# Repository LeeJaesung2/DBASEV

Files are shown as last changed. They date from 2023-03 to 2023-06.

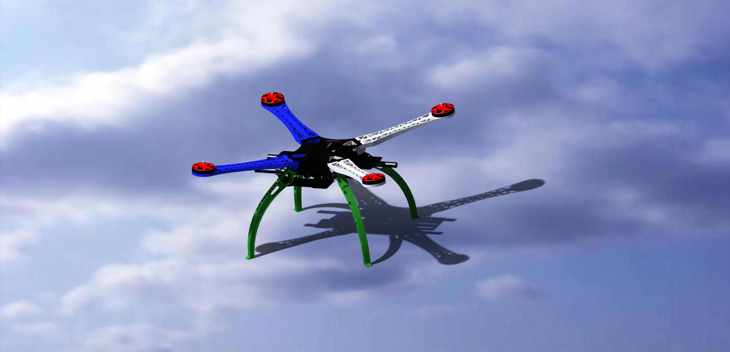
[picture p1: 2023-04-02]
Drone Modeling/Drone Modeling/test.jpg

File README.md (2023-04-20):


## 🚒🚑**드론을 이용한 긴급차량 지원 시스템**이란?

드론을 통해 긴급차량이 신속하게 사고현장에 도착하여 **골든타임**을 확보할 수 있는 긴급차량 지원 시스템 
<br><br>

## 📌 주요 기능
**긴급차량 추월로 확보**- 긴급차량보다 선행하여 전방 100M에서 차량들에게 긴급상황을 미리 알려줍니다.<br>
<br>



## 📆 개발 일정
기획 (23.02.20 ~ 23.03)<br>
제품 모델링 (23.03.27 ~ 23.)<br>
비행제어 SW (23.03.27 ~ 23.)<br>
제작 (23.04. ~ 23.)<br>
시험비행 (23. ~ 23.)<br>

## ⌨ How To Use?

### 1. 파이썬 2.7, ttb 설치
chomod +x install.sh <br />
./install.sh

### 2. 드론킷(droneKit) 설치
chomod +x dronekit.sh <br />
./dronekit.sh

### 3. 헤더파일 설치 (Linux)
sudo make install

### 4. 컴파일 (Linux)
sudo make

### 5. 실행
sudo make exedrone (드론 실행파일) <br />
sudo make exevhicle (차량 실행파일)

### 6. 실행파일 지우기
sudo make clean

## 😀 함께한 사람들
경상국립대학교 항공우주 및 소프트웨어공학과 18학번 이재성<br>
경상국립대학교 항공우주 및 소프트웨어공학과 18학번 이선호<br>
경상국립대학교 항공우주 및 소프트웨어공학과 22학번 이지훈<br>
경상국립대학교 항공우주 및 소프트웨어공학과 18학번 정승진<br>
경상국립대학교 항공우주 및 소프트웨어공학과 18학번 한규영

## 📗 참고 자료<br>
Notion : https://www.notion.so/Sky-Rescuers-cc621ae866ca4cde91c4affb1fb3adff<br>

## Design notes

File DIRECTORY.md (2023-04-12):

DBASEV   
├── build
|    ├── drivers 
|    ├── modules 
├── docs -- 문서
├── Dron Modeling 
├── pixhawk  
|    ├── Documentation 
|    ├── example 
├── python_src -- python 코드
├── rasberryPi -- 라즈베리파이 코드  
|    ├── drone -- 드론 코드  
|    ├── vehicle -- 차량 코드  
├── src 소스코드  
|    ├── drivers -- 장치 세팅  
|    ├── examples -- 예제코드  
|    ├── include -- 라이브러리 목록  
|    ├── modules -- 기능 구현 코드  
├── test -- 테스트 코드  
├── test_data -- 테스트 데이터  
├── Makefile  
├── README.md

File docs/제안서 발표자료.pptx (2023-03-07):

## 자율비행 드론을 이용한 긴급차량 지원 시스템 S A V e D

System for Assistancd emergency Vehicle traffic using autonomos flying Drone

이재성 2018011889
이선호 2018011886
이지훈 2022080184
정승진 2018011911
한규영 2018011939

## CONTENTS

1. 추진배경
2. 목표
3. 기업의 요구도
4. 개발 내용
5. 결과물
6. 기대효과
7. 현실적 제한요소
8. 팀 구성 및 역할 분담
9. 예산 및 일정

## 추진 배경

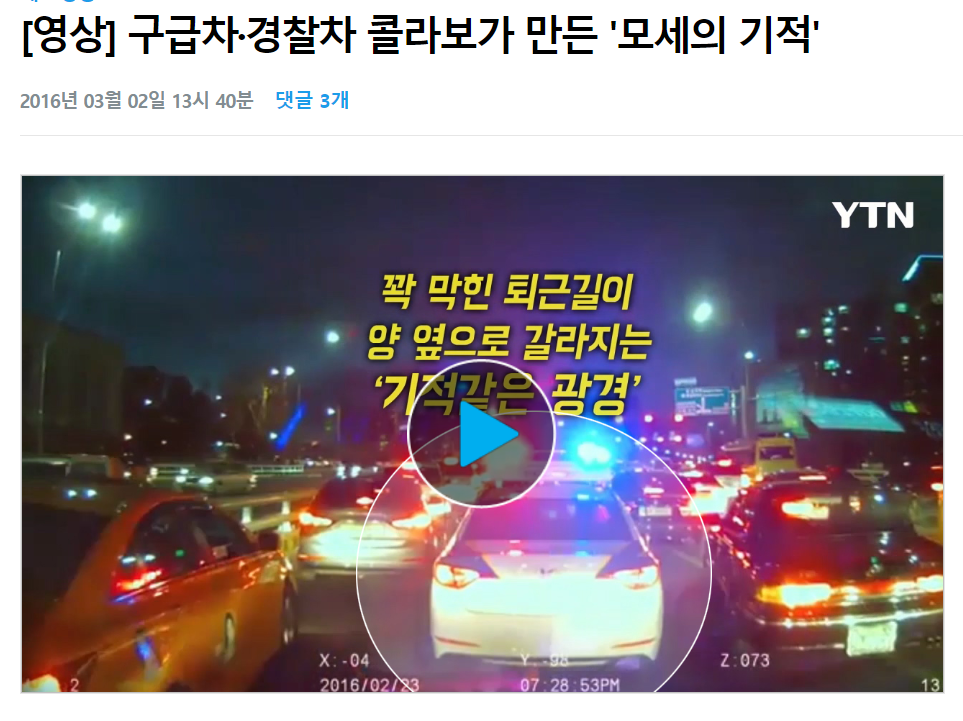
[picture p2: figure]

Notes: http://www.headlinejeju.co.kr/news/articleView.html?idxno=493822
http://www.ihalla.com/article.php?aid=1660275907730641044
https://news.sbs.co.kr/news/endPage.do?news_id=N1006625344&plink=ORI&cooper=NAVER

## 추진 배경

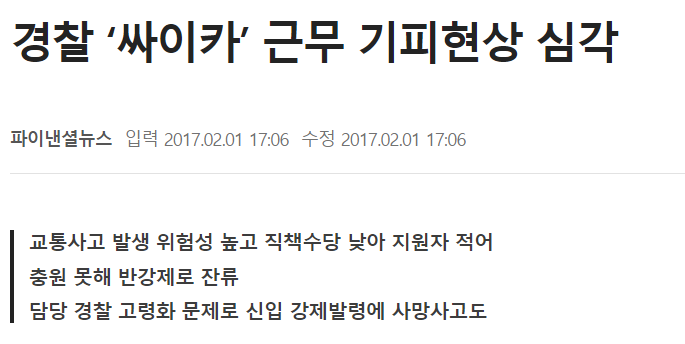
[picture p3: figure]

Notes: https://www.fnnews.com/news/201702011706314263

## 과제의 목표

## 기업 요구도

## 개발 내용

## 결과물

## 기대 효과

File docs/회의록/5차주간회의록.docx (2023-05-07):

주 간 회 의 록

팀 명 | Sky Rescuers | 차수 | 5차
일 시 | 2023년 5월 7일 일요일 18시 30분
장 소 | 창업보육센터 C동 102호
참석자 | 이재성, 이선호, 이지훈, 정승진, 한규영
불참자
주요안건 | 물품 추가주문, 진행상황 공유

회의내용

- 지난주 진행상황
1. 드론 납땜 및 조립
2. 미션플래너 Navigation, Do 명령어 정리 및 각각 파라미터 설정 후 데이터 포맷 작성
3. 속도조절 알고리즘, next stoppoint설정 알고리즘, 통신오류에 대한 알고리즘 작성
4. Thread간 concurrent queue 연결
5. python코드를 임베딩하는 Makefile 수정
- 이번주 진행상황 (진행상황을 나타내는 사진 등 첨부)
1. 추가 물품 주문 (GPS, 자이로센서, 피에조 부저, 네오픽셀 등)
2. 설계 변경에 의한 메세지큐 연결
3. matlab을 이용한 차량과 드론의 거리 유지 제어 블럭도 제작
4. 비행 소프트웨어의 소프트웨어 추가 구현 및 코드 리펙토링
5. GPS를 이용한 차량 속력 계산 프로그램 구현
6. 탑재체 부착 케이스 모델링
7. 드론 켈리브레이션 조정 완료
- 문제점
1. 도로 상황을 가정한 시뮬레이션 방안 필요
2. 커넥트 문제를 해결 후 테스트 필요
3. 메세지 큐를 C++에서 정보 생성후 python에서 받아야 하는데 python 코드에서 하드웨어를 건드리는데 어려움이 있음
- 해결방안

1. posix_ipc라이브러리를 이용하여 큐에 접근해야함

2. unity를 이용한 시뮬레이션, 더미데이터를 이용한 시뮬레이션

- 팀원 별 실천사항(각 팀원에 부여된 역할을 명확히 명시할 것)

메세지 큐를 이용하기 위한 C++ producer code 작성

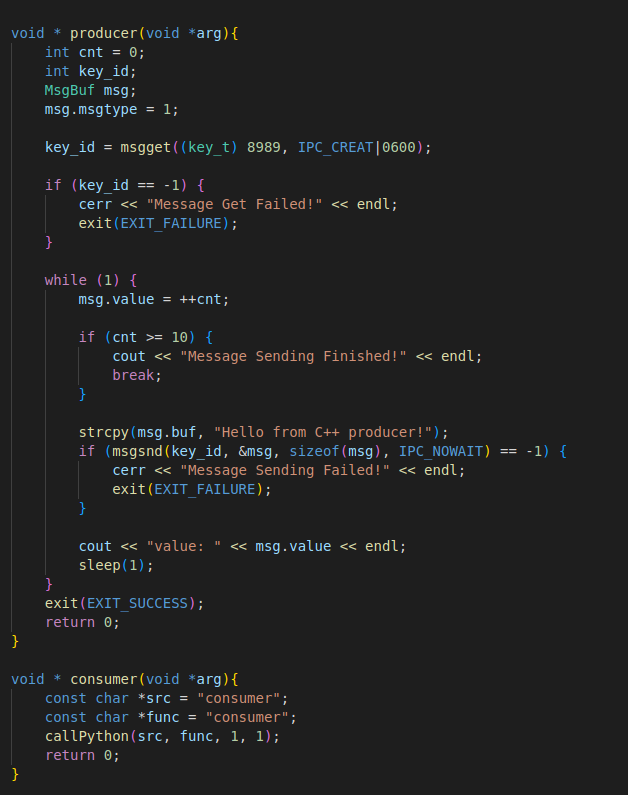
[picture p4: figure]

python consumer code 작성

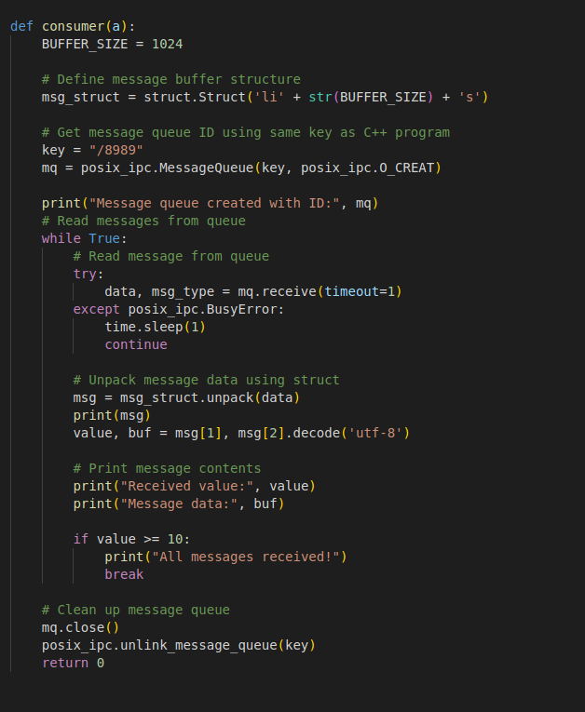
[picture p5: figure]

두 프로그램을 멀티 스레드 프로그램을 이용하여 실행 결과

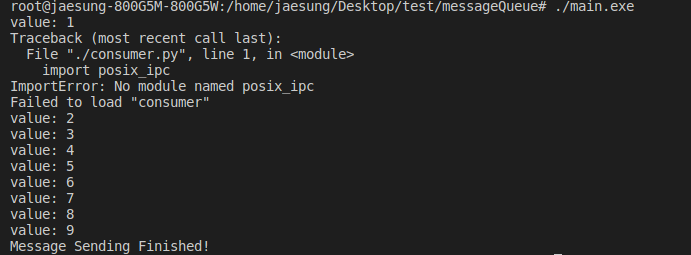
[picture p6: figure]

producer 코드에서 push 작동은 확인 하였지만 python 코드에서는 큐의 접근이 되지 않음

posix_ipc 라이브러리를 이용하여 자원에 접근하는 코드를 작성해야함

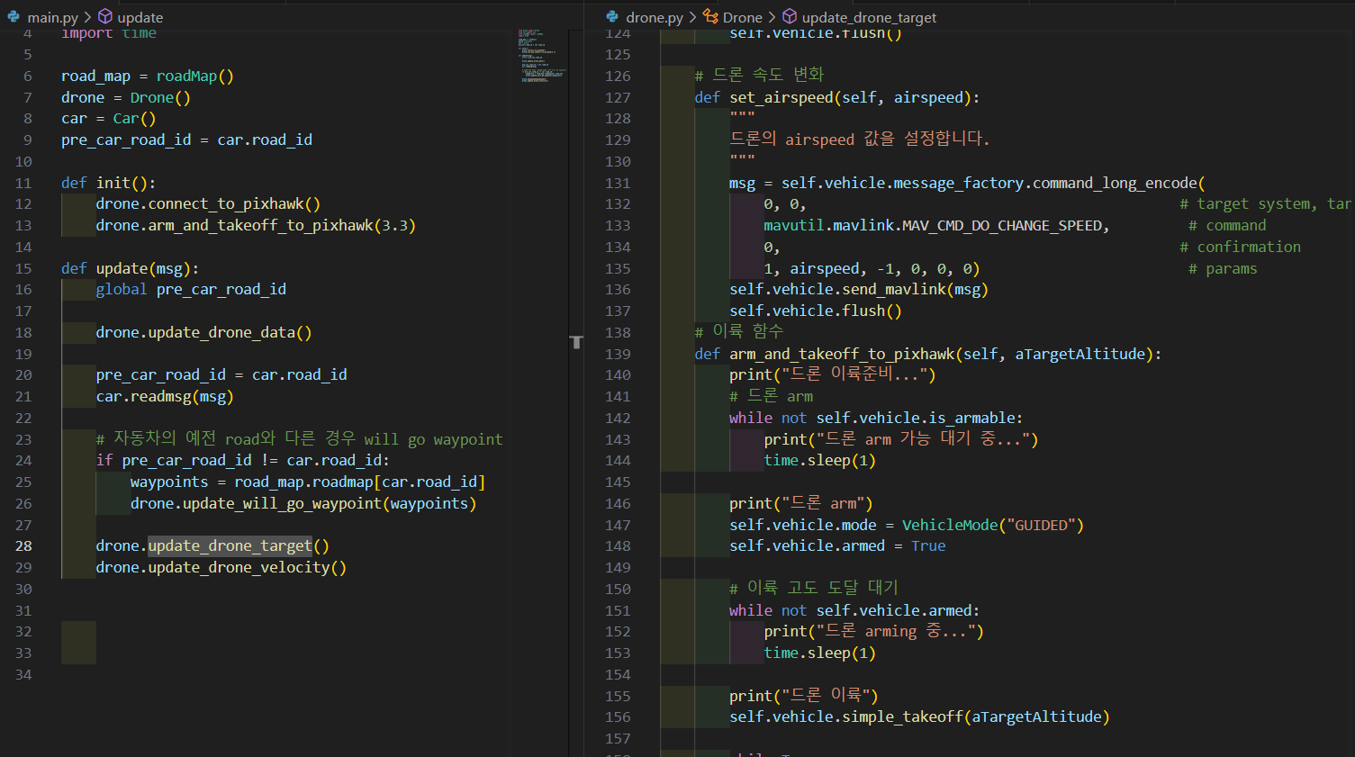
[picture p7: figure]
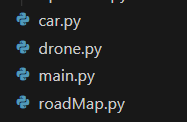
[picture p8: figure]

drone, car, road_map 객체를 만들었다. 이전에는 객체를 사용하지 않아서 코드의 흐름이 복잡하고 코드를 수정하기 힘들었다. 또한 실제 사용하는 코드에서는 plot부분이나 plot을 그리기위한 데이터들은 필요 없기에 그러한 부분들을 제거하고 객체를 만듬으로써 유지보수성을 키웠다.

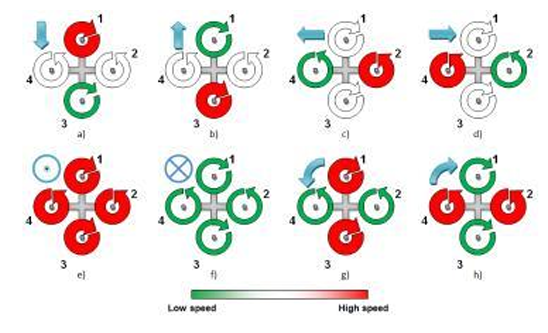
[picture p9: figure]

● 쿼드콥터의 각 모터의 추력의 세기에 대하여 운동방정식을 만들어야한다.

이때 전진비행에 대하여 운동방정식을 구할때 위의 그림에서의 첫번째 쿼드콥터와 같이 1번 모터를 강하게 2,4번은 동일한 힘으로 3번은 약하게 출력해야하지만, 가정하는 운동방정식에서는 1번을 강하게, 2,3,4번 모터을 동일한 힘으로 출력해주어 다음과 같은 운동방정식을 만들었다.

y=((F_1 +3F_0)/m)sin∅

다음 식을 선형화하여 matlab에서 제어 블럭도를 제작하였다.

sin∅ ≈ ∅

y = ((F_1 +3F_0)/m)d∅

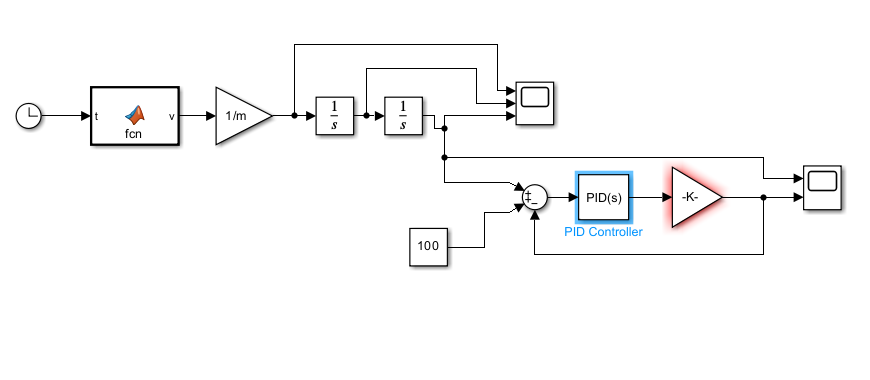
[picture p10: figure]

다음은 차량의 운동방정식에 대한 그래프를 표현하였다.

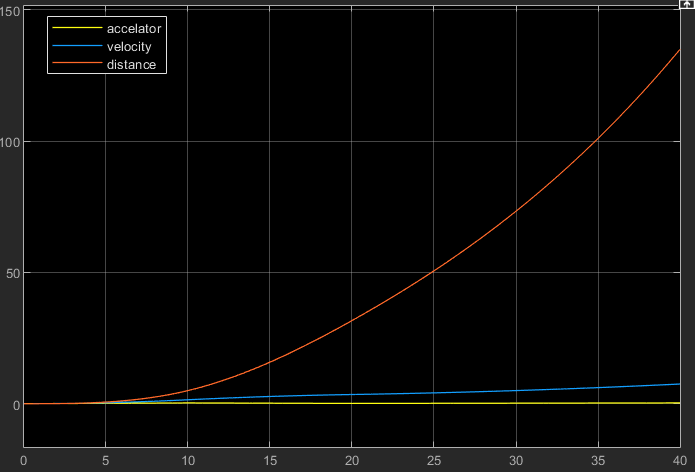
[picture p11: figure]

● 라즈베리파이 부착 아크릴 케이스 모델링

-라즈베리파이가 픽스호크 밑 프레임에 탑재가 불가능하다고 판단하여, 아크릴과 서포트 볼트를 이용하여, 라즈베리파이를 부착할 예정임.

그리고 다른 탑재체들도 다양하게 적용을 시킬 수 있음.

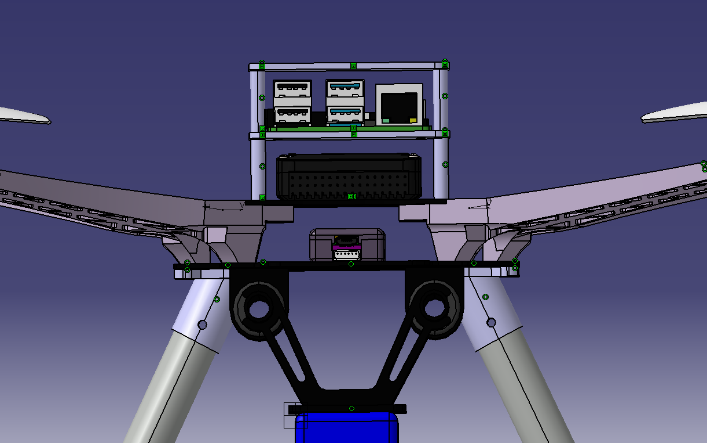
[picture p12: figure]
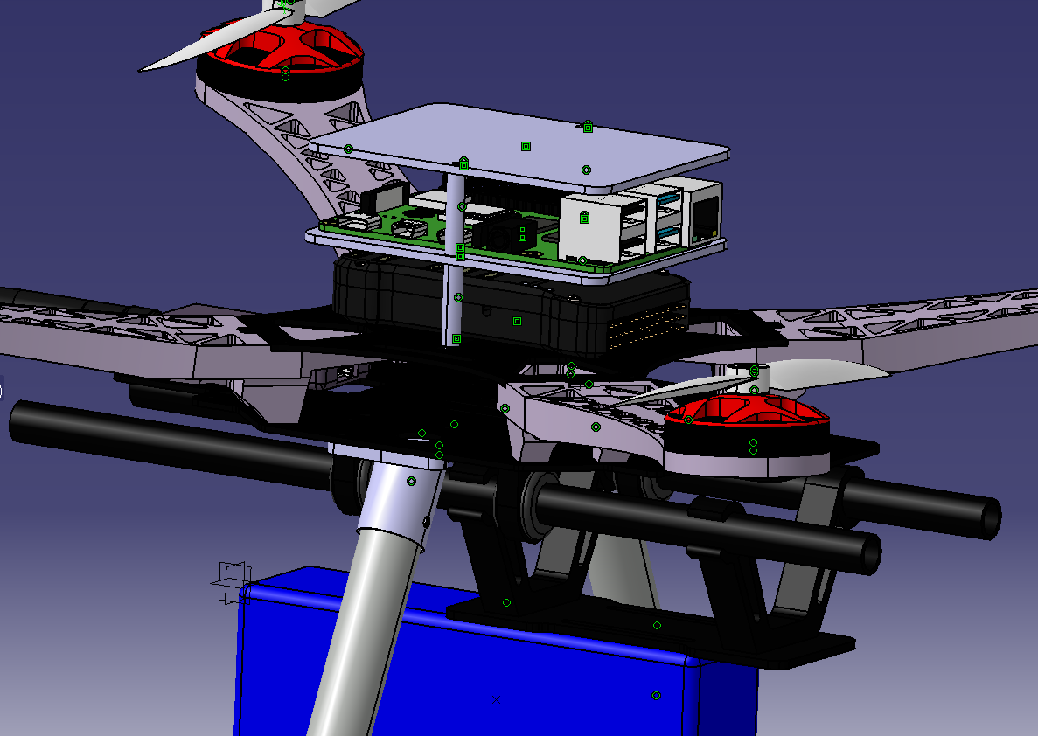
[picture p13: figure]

아크릴을 레이저 프린트로 커팅할 예정임으로, 캐드파일도 생성함.

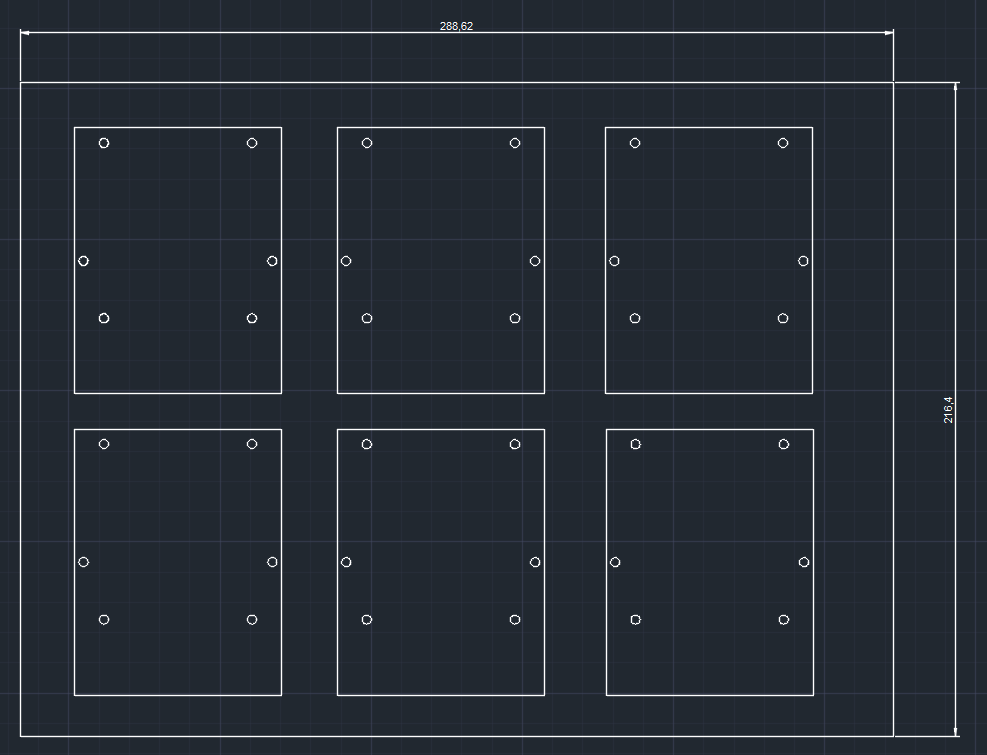
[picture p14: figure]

● GPS를 이용한 차량 속력 계산 프로그램 구현

‘Haversine’ 수식

: 항법에서 사용되는 방정식으로 지구와 같은 구의 표면 상에서 두 점 사이의 거리구할 수 있음

먼저 위도와 경도를 각각 degree 단위에서 radian 단위로 변환해야함. 그 후에 위도와 경도를 이용하여 거리를 구하고 있으며, 두 gps의 시간 term을 이용해 속력을 구하고 있음.

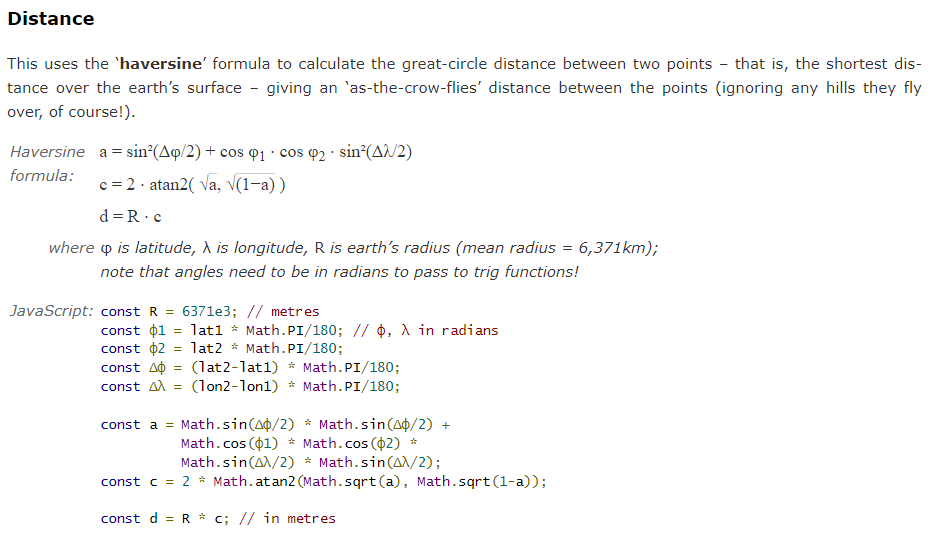
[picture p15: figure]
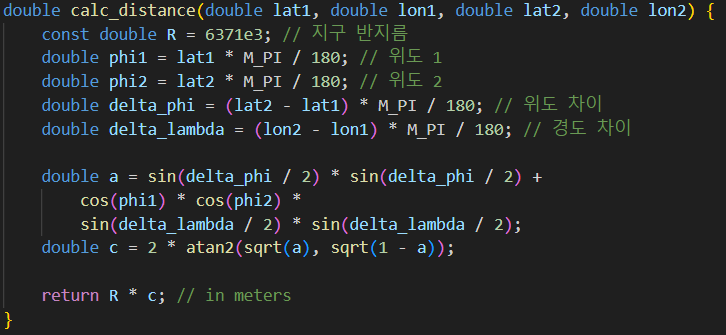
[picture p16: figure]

다음 모임 시간/장소: 2023년 5월 12일 금

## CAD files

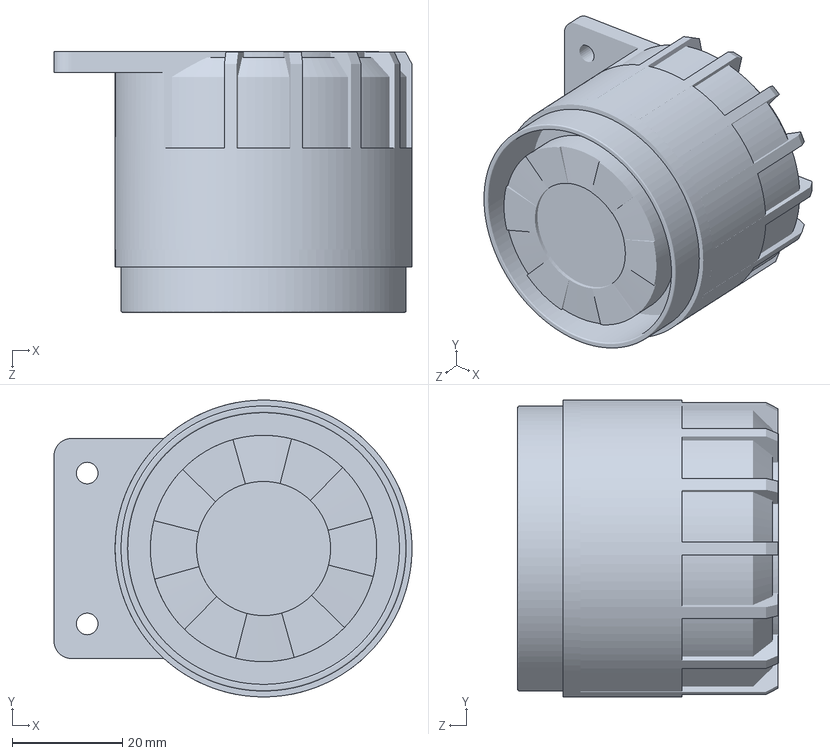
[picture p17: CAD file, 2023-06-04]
drone part/새 폴더/1234.SLDPRT
65.1 x 54.0 x 47.4 mm

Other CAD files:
Drone Modeling/Drone Modeling/5040 prop cw.CATPart
Drone Modeling/Drone Modeling/5040PropCCW.CATPart
Drone Modeling/Drone Modeling/5040prop.CATPart
Drone Modeling/Drone Modeling/Battery Plate Support.CATPart
Drone Modeling/Drone Modeling/Battery Plate.CATPart
Drone Modeling/Drone Modeling/Bottom Plate.CATPart
Drone Modeling/Drone Modeling/Leg.CATPart
Drone Modeling/Drone Modeling/Part27.CATPart
Drone Modeling/Drone Modeling/Part28.CATPart
Drone Modeling/Drone Modeling/Part29.CATPart
Drone Modeling/Drone Modeling/Part30.CATPart
Drone Modeling/Drone Modeling/Part31.CATPart
Drone Modeling/Drone Modeling/Part32.CATPart
Drone Modeling/Drone Modeling/Part33.CATPart
Drone Modeling/Drone Modeling/Part34.CATPart
Drone Modeling/Drone Modeling/Part35.CATPart
Drone Modeling/Drone Modeling/Part36.CATPart
Drone Modeling/Drone Modeling/Part43.CATPart
Drone Modeling/Drone Modeling/Part44.CATPart
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

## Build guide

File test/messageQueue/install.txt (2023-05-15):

pip install posix_ipc==1.0.4
pip install sysv-ipc==1.0.1

https://github.com/kiyoon/C_python_ipc/blob/master/receiver.py

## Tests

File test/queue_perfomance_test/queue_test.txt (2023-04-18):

install ttb using ttb.sh

copile option
g++ concurrent_queue.cpp -pthread -ltbb -std=c++14

change Max and test

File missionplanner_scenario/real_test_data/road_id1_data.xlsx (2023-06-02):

road_id | waypoint_id | lat | lon | alt
1 | 1 | 35.1554345 | 128.1040969 | 3
1 | 2 | 35.1553926 | 128.1041161 | 3
1 | 3 | 35.1553504 | 128.1041358 | 3
1 | 4 | 35.1553084 | 128.104155 | 3
1 | 5 | 35.1552665 | 128.1041744 | 3
1 | 6 | 35.155224 | 128.1041938 | 3
1 | 7 | 35.1551821 | 128.1042133 | 3
1 | 8 | 35.1551398 | 128.1042324 | 3
1 | 9 | 35.1550982 | 128.1042529 | 3
1 | 10 | 35.155056 | 128.1042726 | 3
1 | 11 | 35.155014 | 128.1042911 | 3
1 | 12 | 35.1549721 | 128.1043098 | 3
1 | 13 | 35.1549304 | 128.1043303 | 3
1 | 14 | 35.1548882 | 128.1043484 | 3
1 | 15 | 35.1548469 | 128.1043689 | 3
1 | 16 | 35.1548046 | 128.1043888 | 3
1 | 17 | 35.1547624 | 128.1044084 | 3
1 | 18 | 35.1547202 | 128.1044262 | 3
1 | 19 | 35.1546788 | 128.1044466 | 3
1 | 20 | 35.1546363 | 128.1044658 | 3
1 | 21 | 35.1545946 | 128.1044852 | 3
1 | 22 | 35.1545524 | 128.104505 | 3
1 | 23 | 35.1545105 | 128.1045241 | 3
1 | 24 | 35.1544685 | 128.1045432 | 3
1 | 25 | 35.1544269 | 128.1045633 | 3
1 | 26 | 35.1543852 | 128.1045824 | 3

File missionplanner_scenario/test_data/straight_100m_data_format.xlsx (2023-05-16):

road_id | waypoint_id | latitude(위도) | longtitude(경도) | altitude
1 | 1 | 35.1535098 | 128.1002861 | 5
1 | 2 | 35.1535017 | 128.1003405 | 5
1 | 3 | 35.153494 | 128.1003952 | 5
1 | 4 | 35.1534847 | 128.1004491 | 5
1 | 5 | 35.153477 | 128.1005038 | 5
1 | 6 | 35.1534693 | 128.1005578 | 5
1 | 7 | 35.1534608 | 128.1006118 | 5
1 | 8 | 35.1534523 | 128.1006654 | 5
1 | 9 | 35.1534447 | 128.1007197 | 5
1 | 10 | 35.1534351 | 128.100773 | 5
1 | 11 | 35.1534271 | 128.1008267 | 5
1 | 12 | 35.1534208 | 128.1008813 | 5
1 | 13 | 35.1534126 | 128.100935 | 5
1 | 14 | 35.1534038 | 128.1009893 | 5
1 | 15 | 35.1533948 | 128.1010436 | 5
1 | 16 | 35.1533868 | 128.1010972 | 5
1 | 17 | 35.1533789 | 128.1011509 | 5
1 | 18 | 35.1533701 | 128.1012052 | 5
1 | 19 | 35.1533613 | 128.1012592 | 5
1 | 20 | 35.1533517 | 128.1013132 | 5
1 | 21 | 35.1533446 | 128.1013675 | 5
1 | 22 | 35.1533369 | 128.1014218 | 5
1 | 23 | 35.1533298 | 128.1014758 | 5
1 | 24 | 35.153321 | 128.1015294 | 5
1 | 25 | 35.1533134 | 128.1015834 | 5
1 | 26 | 35.1533043 | 128.1016374 | 5
1 | 27 | 35.1532961 | 128.101691 | 5
1 | 28 | 35.1532879 | 128.1017447 | 5
1 | 29 | 35.1532796 | 128.1017993 | 5
1 | 30 | 35.15327 | 128.1018529 | 5
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

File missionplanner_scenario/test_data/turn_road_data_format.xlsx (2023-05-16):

road_id | waypoint_id | latitude(위도) | longtitude(경도) | altitude
1 | 1 | 35.1535098 | 128.1002861 | 5
1 | 2 | 35.1535017 | 128.1003405 | 5
1 | 3 | 35.153494 | 128.1003952 | 5
1 | 4 | 35.1534847 | 128.1004491 | 5
1 | 5 | 35.153477 | 128.1005038 | 5
1 | 6 | 35.1534693 | 128.1005578 | 5
1 | 7 | 35.1534608 | 128.1006118 | 5
1 | 8 | 35.1534523 | 128.1006654 | 5
1 | 9 | 35.1534447 | 128.1007197 | 5
1 | 10 | 35.1534351 | 128.100773 | 5
1 | 11 | 35.1534271 | 128.1008267 | 5
1 | 12 | 35.1534208 | 128.1008813 | 5
1 | 13 | 35.1534126 | 128.100935 | 5
1 | 14 | 35.1534038 | 128.1009893 | 5
1 | 15 | 35.1533948 | 128.1010436 | 5
1 | 16 | 35.1533868 | 128.1010972 | 5
1 | 17 | 35.1533789 | 128.1011509 | 5
1 | 18 | 35.1533701 | 128.1012052 | 5
1 | 19 | 35.1533613 | 128.1012592 | 5
1 | 20 | 35.1533517 | 128.1013132 | 5
1 | 21 | 35.1533446 | 128.1013675 | 5
1 | 22 | 35.1533369 | 128.1014218 | 5
1 | 23 | 35.1533298 | 128.1014758 | 5
1 | 24 | 35.153321 | 128.1015294 | 5
1 | 25 | 35.1533134 | 128.1015834 | 5
1 | 26 | 35.1533043 | 128.1016374 | 5
1 | 27 | 35.1532961 | 128.101691 | 5
1 | 28 | 35.1532879 | 128.1017447 | 5
1 | 29 | 35.1532796 | 128.1017993 | 5
1 | 30 | 35.15327 | 128.1018529 | 5
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

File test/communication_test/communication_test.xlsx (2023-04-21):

 |  |  |  |  |  |  |  |  |  | avg
 |  |  |  |  |  | 5119 | 7935 | 5887 | 9983 | 7231
msec | 100 | 300 | 500 | 700 | 1000
1 | 83 | 169 | 198 | 120 | 357
2 | 98 | 85 | 85 | 234 | 283
3 | 83 | 79 | 68 | 170 | 226
4 | 86 | 206 | 78 | 194 | 312
5 | 89 | 85 | 84 | 170 | 170
6 | 83 | 149 | 170 | 164 | 288
7 | 92 | 85 | 79 | 204 | 363
8 | 84 | 85 | 163 | 170 | 303
9 | 85 | 68 | 120 | 198 | 195
10 | 83 | 122 | 170 | 227 | 227
 | 9983 | 9216 | 9983 | 8275 | 9984
 | 9983 | 9984 | 9984 | 9983 | 9983
 | 9984 | 10239 | 9727 | 9728 | 9727
AVG
 | 100 | 300 | 500 | 700 | 1000
 | 86.6 | 113.3 | 121.5 | 185.1 | 272.4
 | 9380 | 9813 | 9750 | 9328.666667 | 9898

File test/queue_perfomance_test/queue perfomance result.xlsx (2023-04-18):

 | concurrent queuq | queue |  | concurrent queuq | queue |  |  | concurrent queuq | queue |  | concurrent queuq | queue |  | concurrent queuq | queue |  | concurrent queuq | queue
10K | 7 | 4 | 100K | 45 | 47 |  | 1M | 427 | 455 | 10M | 4104 | 4115 | 100M | 41542 | 44172 | 1B | 416650 | 411778
 | 9 | 5 |  | 44 | 46 |  |  | 420 | 492 |  | 4085 | 4896 |  | 42273 | 44997 |  | 409122 | 421276
 | 4 | 5 |  | 50 | 52 |  |  | 421 | 471 |  | 4037 | 5019 |  | 40285 | 45412
 | 4 | 5 |  | 47 | 54 |  |  | 422 | 488 |  | 4095 | 4398 |  | 40867 | 48428
 | 5 | 4 |  | 45 | 51 |  |  | 421 | 439 |  | 4097 | 4592 |  | 41472 | 49453
 | 4 | 4 |  | 48 | 48 |  |  | 422 | 447 |  | 4186 | 4584 |  | 40264 | 46746
 | 5 | 4 |  | 43 | 45 |  |  | 428 | 519 |  | 4233 | 4593 |  | 41094 | 46337
 | 9 | 5 |  | 48 | 50 |  |  | 422 | 422 |  | 4104 | 4285 |  | 40322 | 42703
 | 6 | 5 |  | 44 | 50 |  |  | 419 | 472 |  | 4070 | 4204 |  | 39759 | 42728
 | 5 | 5 |  | 43 | 49 |  |  | 416 | 423 |  | 4152 | 4266 |  | 39860 | 44409
 | 5.8 | 4.6 |  | 45.7 | 49.2 |  |  | 421.8 | 462.8 |  | 4116.3 | 4495.2 |  | 40773.8 | 45538.5 |  | 412886 | 416527
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

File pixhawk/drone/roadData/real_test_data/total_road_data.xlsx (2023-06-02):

road_id | waypoint_id | lat | lon | alt
1 | 1 | 35.1554345 | 128.1040969 | 3
1 | 2 | 35.1553926 | 128.1041161 | 3
1 | 3 | 35.1553504 | 128.1041358 | 3
1 | 4 | 35.1553084 | 128.104155 | 3
1 | 5 | 35.1552665 | 128.1041744 | 3
1 | 6 | 35.155224 | 128.1041938 | 3
1 | 7 | 35.1551821 | 128.1042133 | 3
1 | 8 | 35.1551398 | 128.1042324 | 3
1 | 9 | 35.1550982 | 128.1042529 | 3
1 | 10 | 35.155056 | 128.1042726 | 3
1 | 11 | 35.155014 | 128.1042911 | 3
1 | 12 | 35.1549721 | 128.1043098 | 3
1 | 13 | 35.1549304 | 128.1043303 | 3
1 | 14 | 35.1548882 | 128.1043484 | 3
1 | 15 | 35.1548469 | 128.1043689 | 3
1 | 16 | 35.1548046 | 128.1043888 | 3
1 | 17 | 35.1547624 | 128.1044084 | 3
1 | 18 | 35.1547202 | 128.1044262 | 3
1 | 19 | 35.1546788 | 128.1044466 | 3
1 | 20 | 35.1546363 | 128.1044658 | 3
1 | 21 | 35.1545946 | 128.1044852 | 3
1 | 22 | 35.1545524 | 128.104505 | 3
1 | 23 | 35.1545105 | 128.1045241 | 3
1 | 24 | 35.1544685 | 128.1045432 | 3
1 | 25 | 35.1544269 | 128.1045633 | 3
1 | 26 | 35.1543852 | 128.1045824 | 3
2 | 1 | 35.1543528 | 128.1045948 | 3
2 | 2 | 35.1543109 | 128.1046136 | 3
2 | 3 | 35.154269 | 128.1046327 | 3
2 | 4 | 35.1542267 | 128.1046525 | 3
2 | 5 | 35.1541848 | 128.1046719 | 3
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

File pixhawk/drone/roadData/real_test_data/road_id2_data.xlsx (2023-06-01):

road_id | waypoint_id | latitude(위도) | longtitude(경도) | altitude
2 | 1 | 35.1543528 | 128.1045948 | 3
2 | 2 | 35.1543109 | 128.1046136 | 3
2 | 3 | 35.154269 | 128.1046327 | 3
2 | 4 | 35.1542267 | 128.1046525 | 3
2 | 5 | 35.1541848 | 128.1046719 | 3
2 | 6 | 35.1541423 | 128.1046911 | 3
2 | 7 | 35.1541135 | 128.1047038 | 3

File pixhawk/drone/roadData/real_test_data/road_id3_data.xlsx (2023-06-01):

road_id | waypoint_id | latitude(위도) | longtitude(경도) | altitude
3 | 1 | 35.1543841 | 128.1046156 | 3
3 | 2 | 35.1543956 | 128.1046688 | 3
3 | 3 | 35.1544071 | 128.1047219 | 3
3 | 4 | 35.1544186 | 128.1047751 | 3
3 | 5 | 35.1544301 | 128.1048282 | 3

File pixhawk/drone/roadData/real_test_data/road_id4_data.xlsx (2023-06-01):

road_id | waypoint_id | latitude(위도) | longtitude(경도) | altitude
4 | 1 | 35.1543704 | 128.1045506 | 3
4 | 2 | 35.1543591 | 128.1044976 | 3
4 | 3 | 35.1543482 | 128.1044443 | 3
4 | 4 | 35.1543367 | 128.1043907 | 3
4 | 5 | 35.1543257 | 128.1043377 | 3
4 | 6 | 35.1543142 | 128.104284 | 3
4 | 7 | 35.1543032 | 128.1042311 | 3
4 | 8 | 35.1542914 | 128.1041778 | 3

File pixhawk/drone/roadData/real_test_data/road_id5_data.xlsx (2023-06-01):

road_id | waypoint_id | latitude(위도) | longtitude(경도) | altitude
5 | 1 | 35.1544608 | 128.10485 | 3
5 | 2 | 35.1545011 | 128.1048254 | 3
5 | 3 | 35.1545413 | 128.1048007 | 3
5 | 4 | 35.1545816 | 128.1047761 | 3
5 | 5 | 35.1546218 | 128.1047514 | 3
5 | 6 | 35.1546621 | 128.1047268 | 3
5 | 7 | 35.1547023 | 128.1047021 | 3
5 | 8 | 35.1547425 | 128.1046775 | 3
5 | 9 | 35.1547827 | 128.1046528 | 3

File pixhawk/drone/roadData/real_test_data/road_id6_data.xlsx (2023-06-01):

road_id | waypoint_id | latitude(위도) | longtitude(경도) | altitude
6 | 1 | 35.1544513 | 128.1048989 | 3
6 | 2 | 35.1544656 | 128.1049509 | 3
6 | 3 | 35.1544798 | 128.1050029 | 3

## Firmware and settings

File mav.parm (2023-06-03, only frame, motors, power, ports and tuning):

ATC_ANGLE_BOOST  1.000000
ATC_ANG_LIM_TC   1.000000
ATC_ANG_PIT_P    4.500000
ATC_ANG_RLL_P    4.500000
ATC_ANG_YAW_P    4.500000
ATC_RATE_FF_ENAB 1.000000
ATC_RATE_P_MAX   0.000000
ATC_RATE_R_MAX   0.000000
ATC_RATE_Y_MAX   0.000000
ATC_RAT_PIT_D    0.003600
ATC_RAT_PIT_FF   0.000000
ATC_RAT_PIT_FLTD 20.000000
ATC_RAT_PIT_FLTE 0.000000
ATC_RAT_PIT_FLTT 20.000000
ATC_RAT_PIT_I    0.135000
ATC_RAT_PIT_IMAX 0.500000
ATC_RAT_PIT_P    0.135000
ATC_RAT_PIT_SMAX 0.000000
ATC_RAT_RLL_D    0.003600
ATC_RAT_RLL_FF   0.000000
ATC_RAT_RLL_FLTD 20.000000
ATC_RAT_RLL_FLTE 0.000000
ATC_RAT_RLL_FLTT 20.000000
ATC_RAT_RLL_I    0.135000
ATC_RAT_RLL_IMAX 0.500000
ATC_RAT_RLL_P    0.135000
ATC_RAT_RLL_SMAX 0.000000
ATC_RAT_YAW_D    0.000000
ATC_RAT_YAW_FF   0.000000
ATC_RAT_YAW_FLTD 0.000000
ATC_RAT_YAW_FLTE 2.500000
ATC_RAT_YAW_FLTT 20.000000
ATC_RAT_YAW_I    0.018000
ATC_RAT_YAW_IMAX 0.500000
ATC_RAT_YAW_P    0.180000
ATC_RAT_YAW_SMAX 0.000000
BATT2_MONITOR    0.000000
BATT3_MONITOR    0.000000
BATT4_MONITOR    0.000000
BATT5_MONITOR    0.000000
BATT6_MONITOR    0.000000
BATT7_MONITOR    0.000000
BATT8_MONITOR    0.000000
BATT9_MONITOR    0.000000
BATT_MONITOR     0.000000
FLTMODE1         0.000000
FLTMODE2         0.000000
FLTMODE3         0.000000
FLTMODE4         0.000000
FLTMODE5         0.000000
FLTMODE6         6.000000
FLTMODE_CH       5.000000
FRAME_CLASS      1.000000
FRAME_TYPE       1.000000
INS_GYRO_FILTER  20.000000
INS_HNTCH_ENABLE 0.000000
MOT_BAT_CURR_MAX 0.000000
MOT_BAT_CURR_TC  5.000000
MOT_BAT_IDX      0.000000
MOT_BAT_VOLT_MAX 0.000000
MOT_BAT_VOLT_MIN 0.000000
MOT_BOOST_SCALE  0.000000
MOT_HOVER_LEARN  2.000000
MOT_PWM_MAX      2000.000000
MOT_PWM_MIN      1000.000000
MOT_PWM_TYPE     4.000000
MOT_SAFE_DISARM  0.000000
MOT_SAFE_TIME    1.000000
MOT_SLEW_DN_TIME 0.000000
MOT_SLEW_UP_TIME 0.000000
MOT_SPIN_ARM     0.100000
MOT_SPIN_MAX     0.950000
MOT_SPIN_MIN     0.150000
MOT_SPOOL_TIME   0.500000
MOT_THST_EXPO    0.650000
MOT_THST_HOVER   0.687500
MOT_YAW_HEADROOM 200.000000
SERIAL0_BAUD     115.000000
SERIAL0_PROTOCOL 2.000000
SERIAL1_BAUD     57.000000
SERIAL1_OPTIONS  0.000000
SERIAL1_PROTOCOL 2.000000
SERIAL2_BAUD     57.000000
SERIAL2_OPTIONS  0.000000
SERIAL2_PROTOCOL 2.000000
SERIAL3_BAUD     38.000000
SERIAL3_OPTIONS  0.000000
SERIAL3_PROTOCOL 5.000000
SERIAL4_BAUD     38.000000
SERIAL4_OPTIONS  0.000000
SERIAL4_PROTOCOL 5.000000
SERIAL5_BAUD     57.000000
SERIAL5_OPTIONS  0.000000
SERIAL5_PROTOCOL -1.000000
SERVO1_FUNCTION  33.000000
SERVO1_MAX       2000.000000
SERVO1_MIN       1000.000000
SERVO1_REVERSED  0.000000
SERVO1_TRIM      1000.000000
SERVO2_FUNCTION  34.000000
SERVO2_MAX       2000.000000
SERVO2_MIN       1000.000000
SERVO2_REVERSED  0.000000
SERVO2_TRIM      1000.000000
SERVO3_FUNCTION  35.000000
SERVO3_MAX       2000.000000
SERVO3_MIN       1000.000000
SERVO3_REVERSED  0.000000
SERVO3_TRIM      1000.000000
SERVO4_FUNCTION  36.000000
SERVO4_MAX       2000.000000
SERVO4_MIN       1000.000000
SERVO4_REVERSED  0.000000
SERVO4_TRIM      1000.000000
SERVO5_FUNCTION  0.000000
SERVO5_MAX       1900.000000
SERVO5_MIN       1100.000000
SERVO5_REVERSED  0.000000
SERVO5_TRIM      1500.000000
SERVO6_FUNCTION  0.000000
SERVO6_MAX       1900.000000
SERVO6_MIN       1100.000000
SERVO6_REVERSED  0.000000
SERVO6_TRIM      1500.000000
SERVO7_FUNCTION  0.000000
SERVO7_MAX       1900.000000
SERVO7_MIN       1100.000000
SERVO7_REVERSED  0.000000
SERVO7_TRIM      1500.000000
SERVO8_FUNCTION  0.000000
SERVO8_MAX       1900.000000
SERVO8_MIN       1100.000000
SERVO8_REVERSED  0.000000
SERVO8_TRIM      1500.000000
SERVO9_FUNCTION  0.000000
SERVO9_MAX       1900.000000
SERVO9_MIN       1100.000000
SERVO9_REVERSED  0.000000
SERVO9_TRIM      1500.000000

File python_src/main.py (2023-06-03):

from drone import Drone
from car import Car
from messagequeue import mq_init, pop
import time

def init(drone):
    drone.connect_to_pixhawk()
    #drone.sim_connect_to_pixhawk()
    drone.arm_and_takeoff_to_pixhawk(7.0)
    

def update(msg, roadMap, car, drone, pre_car_road_id):

    drone.update_drone_data()

    pre_car_road_id = car.road_id

    car.update_car_data(msg)

    # car pre road is not match update will go waypoint update
    if pre_car_road_id != car.road_id:
        waypoints = roadMap[car.road_id]
        drone.update_will_go_waypoint(waypoints)
        drone.add_waypoints_to_pixhawk(waypoints)
    
    drone.update_drone_target()

    car_data = car.get_car_data()
    drone.update_drone_velocity(car_data)
    
    drone.set_airspeed_to_pixhawk(drone.velocity)

    return pre_car_road_id

def init_make_logfile():
    with open("logfile.txt", "w") as file:
        file.write("time,car_speed,car_road_id,car_waypoint_id,drone_target_speed,drone_speed,drone_road_id,drone_waypoint_id\n")

def add_logfile(data):
    with open("logfile.txt", "a") as file:
        file.write(data)

def flight_control(a):
    # Get message queue ID using same key as C++ program
    key = 5656
    mq = mq_init(key)
    starttime = time.time()


    roadMap = {1: [[1, 1, 35.1520036, 128.1010298, 7.0], [1, 2, 35.1519729, 128.1011331, 7.0], [1, 3, 35.1519423, 128.1012366, 7.0], [1, 
4, 35.1519117, 128.10134, 7.0], [1, 5, 35.151881, 128.1014436, 7.0], [1, 6, 35.1518504, 128.1015469, 7.0], [1, 7, 35.1518198, 128.1016501, 7.0], [1, 8, 35.1517889, 128.1017537, 7.0], [1, 9, 35.1517584, 128.101857, 7.0], [1, 10, 35.1517279, 128.1019603, 7.0], [1, 11, 35.1516971, 128.1020642, 7.0], [1, 12, 35.1516666, 128.1021673, 7.0], [1, 13, 35.151636, 128.1022704, 
7.0]], 2: [[2, 1, 35.1516449, 128.1022955, 7.0], [2, 2, 35.1517289, 128.1023351, 7.0], [2, 3, 35.1518131, 128.102374, 7.0]], 3: [[3, 1, 35.1516302, 128.102291, 7.0], [3, 2, 35.1516006, 128.1023948, 7.0], [3, 3, 35.1515695, 128.1024979, 7.0], [3, 
4, 35.1515384, 128.1026009, 7.0]], 4: [[4, 1, 35.151628, 128.1022865, 7.0], [4, 2, 35.1515447, 128.1022449, 7.0], [4, 3, 35.1514622, 128.1022013, 7.0], [4, 4, 35.1513796, 128.1021577, 7.0]], 5: [[5, 1, 35.1513627, 128.1021487, 7.0], [5, 2, 35.1512873, 128.1020879, 7.0], [5, 3, 35.1512119, 128.102027, 7.0]], 6: [[6, 1, 35.1513802, 128.1021448, 7.0], [6, 2, 35.151423, 
128.1020477, 7.0], [6, 3, 35.1514657, 128.1019512, 7.0], [6, 4, 35.1515068, 128.1018533, 7.0], [6, 5, 35.1515489, 128.1017564, 7.0], [6, 6, 35.151591, 128.1016595, 7.0]], 7: [[7, 1, 35.1516036, 128.1016307, 7.0], [7, 2, 35.1516452, 128.1015333, 7.0], [7, 3, 35.1516868, 128.1014359, 7.0], [7, 4, 35.1517284, 128.1013385, 7.0], [7, 5, 35.15177, 128.1012411, 7.0]], 8: [[8, 1, 35.1516105, 128.1016628, 7.0], [8, 2, 35.1516793, 128.1017341, 7.0], [8, 3, 35.1517481, 128.1018053, 7.0], [8, 4, 35.1518169, 128.1018766, 7.0], [8, 5, 35.1518857, 128.1019478, 7.0]]}

    drone = Drone()
    car = Car()
    pre_car_road_id = car.road_id

    init_make_logfile()
    init(drone)
    
    while True:
        msg = pop(mq)
    
        pre_car_road_id = update(msg, roadMap, car, drone, pre_car_road_id)
        
        update_time = time.time()
        
        log_data = "{},{},{},{},{},{},{},{}\n".format(update_time-starttime,car.velocity,car.road_id,car.waypoint,drone.velocity,drone.current_speed,drone.road_id,drone.target_waypoint)

        add_logfile(log_data)

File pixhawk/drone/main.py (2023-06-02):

from drone import Drone
from car import Car
from messagequeue import *

roadMap = {1: [[1, 1, 35.1554345, 128.1040969, 3.0], [1, 2, 35.1553926, 128.1041161, 3.0], [1, 3, 35.1553504, 128.1041358, 3.0], [1, 4, 35.1553084, 128.104155, 3.0], [1, 5, 35.1552665, 128.1041744, 3.0], [1, 6, 35.155224, 128.1041938, 3.0], [1, 7, 35.1551821, 
128.1042133, 3.0], [1, 8, 35.1551398, 128.1042324, 3.0], [1, 9, 35.1550982, 128.1042529, 3.0], [1, 10, 35.155056, 128.1042726, 3.0], [1, 11, 35.155014, 128.1042911, 3.0], [1, 12, 35.1549721, 128.1043098, 3.0], [1, 13, 35.1549304, 128.1043303, 3.0], [1, 14, 35.1548882, 128.1043484, 3.0], [1, 15, 35.1548469, 128.1043689, 3.0], [1, 16, 35.1548046, 128.1043888, 3.0], [1, 17, 35.1547624, 128.1044084, 3.0], [1, 18, 35.1547202, 128.1044262, 3.0], [1, 19, 35.1546788, 128.1044466, 3.0], [1, 20, 35.1546363, 128.1044658, 3.0], [1, 21, 35.1545946, 128.1044852, 3.0], [1, 22, 35.1545524, 128.104505, 3.0], [1, 23, 35.1545105, 128.1045241, 3.0], [1, 24, 35.1544685, 128.1045432, 3.0], [1, 25, 35.1544269, 128.1045633, 3.0], [1, 26, 35.1543852, 128.1045824, 3.0]], 2: [[2, 1, 35.1543528, 128.1045948, 3.0], [2, 2, 35.1543109, 128.1046136, 3.0], [2, 3, 35.154269, 128.1046327, 3.0], [2, 4, 35.1542267, 128.1046525, 3.0], [2, 5, 35.1541848, 128.1046719, 3.0], [2, 6, 35.1541423, 128.1046911, 3.0], [2, 7, 35.1541135, 128.1047038, 3.0]], 3: [[3, 1, 35.1543841, 128.1046156, 3.0], [3, 2, 35.1543956, 128.1046688, 3.0], [3, 3, 35.1544071, 
128.1047219, 3.0], [3, 4, 35.1544186, 128.1047751, 3.0], [3, 5, 35.1544301, 128.1048282, 3.0]], 4: [[4, 1, 35.1543704, 128.1045506, 3.0], [4, 2, 35.1543591, 128.1044976, 3.0], [4, 3, 35.1543482, 128.1044443, 3.0], [4, 4, 35.1543367, 128.1043907, 3.0], [4, 5, 35.1543257, 128.1043377, 3.0], [4, 6, 35.1543142, 128.104284, 3.0], [4, 7, 35.1543032, 128.1042311, 3.0], [4, 8, 35.1542914, 128.1041778, 3.0]], 5: [[5, 1, 35.1544608, 128.10485, 3.0], [5, 2, 35.1545011, 128.1048254, 3.0], [5, 3, 35.1545413, 128.1048007, 3.0], [5, 4, 35.1545816, 128.1047761, 3.0], [5, 5, 35.1546218, 128.1047514, 3.0], [5, 6, 35.1546621, 128.1047268, 3.0], [5, 7, 35.1547023, 128.1047021, 3.0], [5, 8, 35.1547425, 128.1046775, 3.0], [5, 9, 35.1547827, 128.1046528, 3.0]], 6: [[6, 1, 35.1544513, 128.1048989, 3.0], [6, 2, 35.1544656, 128.1049509, 3.0], [6, 3, 35.1544798, 128.1050029, 3.0]], 7: [[7, 1, 35.1544175, 128.1048654, 3.0], [7, 2, 35.1543759, 128.1048862, 3.0], [7, 3, 35.1543342, 128.104907, 3.0], [7, 4, 35.1542926, 128.1049278, 3.0], [7, 5, 35.1542509, 128.1049486, 3.0]]
}

drone = Drone()
car = Car()
pre_car_road_id = car.road_id

def init():
    drone.connect_to_pixhawk()
    drone.arm_and_takeoff_to_pixhawk(3.3)

def update(msg):
    global pre_car_road_id

    drone.update_drone_data()

    pre_car_road_id = car.road_id

    car.update_car_data(msg)

    # 자동차의 예전 road와 다른 경우 will go waypoint update
    if pre_car_road_id != car.road_id:
        waypoints = roadMap[car.road_id]
        drone.update_will_go_waypoint(waypoints)
        drone.add_waypoints_to_pixhawk(waypoints)
    
    drone.update_drone_target()

    car_data = car.get_car_data()
    drone.update_drone_velocity(car_data)
    
    drone.set_airspeed_to_pixhawk(drone.velocity)

    # 차량 

'''
def consumer(a):
    # Get message queue ID using same key as C++ program
    key = 5656
    mq = mq_init(key)

    # Read messages from queue
    while True:
        # Read message from queue
        value, msg = pop(mq)

        # Print message contents

        print("Message data:", msg)
'''

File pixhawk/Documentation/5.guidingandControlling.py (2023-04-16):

# orientation | region of interest | servos 등
# target position 이나 velocity 속성으로 드론 움직임 조종 가능
from dronekit import connect, VehicleMode
import time

# 기본 시작 코드
vehicle = connect("/dev/ttyAMA0", wait_ready=True, baud=57600)
vehicle.mode = VehicleMode("GUIDED")
vehicle.armed = True
while not vehicle.mode.name =='GUIDED' and not vehicle.armed and not api.exit:
    print (" Getting ready to take off ...")
    time.sleep(1)

# 특정 (위도 경도 고도) 에 가라
a_location = LocationGlobalRelative(-34.3641114, 149.166022, 30)
vehicle.simple_goto(a_location)

# 특정 속도를 내어라
vehicle.airspeed = 5 # m/s
vehicle.groundspeed = 7.5

# 특정 위치로 특정 속도로 가라
vehicle.simple_goto(a_location, groundspeed=10)

def send_ned_velocity(velocity_x, velocity_y, velocity_z, duration):
    msg = vehicle.message_factory.set_position_target_local_ned_encode(
        0, 0, 0,
        mavutil.mavlink.MAV_FRAME_LOCAL_NED,
        
    )

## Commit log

2023-03-08 docs : add ppt
    [종합설계 001반 물품 구입 주문서(학과예산)_2023.xls]
2023-03-08 [Fix] ppt 제목 위치 통일
2023-03-08 PPT 수정
2023-03-16 docs : add relation
    [종합설계 001반 물품 구입 주문서(학과예산)_2023.xls]
2023-03-19 제안서 한글파일 수정
2023-03-19 docs : fix suggestion
    [종합설계 001반 물품 구입 주문서(학과예산)_2023.xls]
2023-03-19 Add files via upload
    수정입니다
2023-03-19 힘들다..
2023-03-22 링크 제안서 - 과제의 목적, 개발동기 및 필요성 작성
2023-03-23 add 선호 sign
2023-03-23 docs : add link docs
    [종합설계 001반 물품 구입 주문서(학과예산)_2023.xls]
2023-03-26 회의록 Update
2023-03-26 주간회의록 update
2023-03-26 승진 추가
2023-03-27 기능별 함수 정리
2023-03-27 docs : add secret file
    [종합설계 001반 물품 구입 주문서(학과예산)_2023.xls]
2023-03-29 픽스호크 라즈베리파이 제어법
2023-03-30 임시 저장
2023-03-31 중간 세이브
2023-03-31 chore : fix directory
    [3.getAttribute.py, 4.takingOff.py, 5.guidingandControlling.py]
2023-04-02 catia file
    add assy, part
    [5040 prop cw.CATPart, 5040PropCCW.CATPart, 5040prop.CATPart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]
2023-04-03 feat : done thread auto compile
2023-04-04 feat : add Makefile for vehicle raspberry pi
2023-04-08 테스트 파일 만드는 중 ...
2023-04-08 dronekit 셸 스크립트 추가
2023-04-08 dronekit 셸 스크립트 위치변경
2023-04-08 dronekit 코드 중간 저장
2023-04-08 dronekit 중간 저장_ 명령어 전달 방법 개편해야함
2023-04-08 아직 읽지는 않았지만 필요한 예시 다가져옴
2023-04-09 명령어 읽기
2023-04-09 파일 입력 형식 update
2023-04-18 test : done concurrent queue perfomance test
    [queue perfomance result.xlsx]
2023-04-18 Make excel file 'realtime waypoint of velocity'
    [Change_of_waypoint_during_30km_h.xlsx, Change_of_waypoint_during_velocity.xlsx]
2023-04-18 Edit data file
    [Change_of_waypoint_during_30km_h.xlsx, Change_of_waypoint_during_velocity.xlsx]
2023-04-20 Edit file and change filename Read_me to scenario.txt
    [Change_of_waypoint_about_velocity.xlsx]
2023-04-21 통신 테스트 파일 추가
    [communication_test.xlsx]
2023-05-05 drone part design
    :)
    [drone_landing_assy.CATProduct, landing_s500.CATPart, pi_up(assy)_V1.CATProduct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]
2023-05-07 [FEAT] 헤더파일 생성
2023-05-07 [FIX] 컴파일 에러 수정
2023-05-14 fixed update drone target data
    [drone.py]
2023-05-16 Add test file
    [straight_100m_data_format.xlsx, turn_road_data_format.xlsx]
2023-05-17 fix : queue log fix
    [messagequeue.py]
2023-05-17 차량 소프트웨어 개발#1
2023-05-19 docs : remove docs file
    [5040 prop cw.CATPart, 5040PropCCW.CATPart, 5040prop.CATPart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]
2023-05-19 [FEAT] imu fuction, Creat Our MapData after directory sorting
2023-05-19 밤샘 회의후 고치기 전 마지막 커밋
    [road_data.xlsx]
2023-05-20 Calcuate road_id, waypoint_id, velocity with GPS
2023-05-25 feat : add WiringPi install
2023-05-25 add relay_test
2023-05-25 relay_test refac
2023-05-26 fixed pixhawk test file
    [drone_setting.py]
2023-05-26 docs : add pin number
2023-05-29 Add simulink pid control position error
2023-05-29 update test file
    [5040 prop cw.CATPart, 5040PropCCW.CATPart, 5040prop.CATPart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]
2023-06-01 refac velocytiy in vehicle_control.cpp
2023-06-01 Add real test data in playground
    [road_id1_data.xlsx, road_id2_data.xlsx, road_id3_data.xlsx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]
2023-06-02 update real map data
    [road_id1_data.xlsx, road_id2_data.xlsx, road_id3_data.xlsx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]
2023-06-03 fix add logfile : mistake data type
    [main.py]
2023-06-03 test : add log file
    [mav.parm]
2023-06-03 i wish i go sleep now
    [roadmap_park_10m.xlsx]
2023-06-04 Delete Drone Modeling directory
    refresh
    [5040 prop cw.CATPart, 5040PropCCW.CATPart, 5040prop.CATPart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]
2023-08-10 fix : ready to flight
    [drone.py]
